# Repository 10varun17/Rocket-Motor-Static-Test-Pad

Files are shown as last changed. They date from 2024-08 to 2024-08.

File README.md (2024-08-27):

# Rocket-Motor-Static-Test-Pad
</br>
This project includes the work that I did during my internship at the Space Technology and Aeronautical Rocketry (STAR) Labs, India in 2022. The objective of my task in the internship was to design a Rocket Motor Static Test Pad for testing and acquiring the required data for the performance analysis of the high powered rocket motors. It is not an individual project. My project had two departments: Avionics and Mechanical Design. There were two members in the Mechanical Design Department and one member (that's me!) in the Avionics Department. I have added my internship report to this repo. Please go through the report to understand the work I did during the internship. The report is an individual report, but during the internship, I was told to put ~80% of my work (avionics) and 20% of my teammates' work in the report. It means that I do not have any contributions to the CAD designs that are presented in my report. My work in the project includes the Avionics work only.</br>

<h2>Notes</h2></br>
You need to have the softwares Proteus and Eagle EDA to open the files in the Circuit Design and PCB design sub-directories. However, I have put some images and pdfs to show my circuit and PCB designs.

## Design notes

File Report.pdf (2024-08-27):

## Internship Report on

# Design and Analysis of Rocket Motor Static Test Pad

## At STAR - Space Technology and Aeronautical Rocketry

## Varun Rayamajhi Avionics Intern Period: 20th August - 19th September

## Duration: 30 Days

INTERNSHIP REPORT | Varun Rayamajhi

## Rocket Motor Static Test Pad

### What is a rocket motor static test pad?

Rocket Motor Static Test Pad is a stationary mechanism designed to hold a rocket motor and conduct its static test fires, during which different parameters of its operation are measured and stored by avionics system for analyzing its performance. These parameters include thrust, chamber pressure, exhaust gas temperature, and so on. Following is a picture of rocket motoe static test pad:-

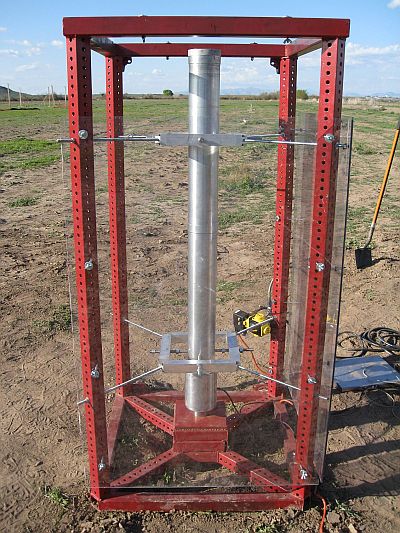
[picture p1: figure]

Figure 1: Rocket Motor Static Test Pad

### Basic Working Principle of Rocket Motor Static Test Pad

Rocket Motor Static Test Pad consists of two prominent components: Frame/Body and Avionics System.

Body
The body of a rocket motor static test pad is used to hold rocket motor statically during static test fires. Depending on the design, the rocket motor can be mounted horizontally or vertically. As well as that, the body of the test pad includes portability mechanism, if it has any. Additionally, it also includes structure to hold controlled fire extinguisher and avionics bay.

Avionics System
Avionics System is a major part of rocket motor static test pad. It is placed inside avionics bay. Avionics System is like the brain of the static test pad which controls the operation of rocket motor, data acquisition, and safety system. Avionics System consists of all electronic components such as temperature sensor, micro controller, load cell, and so on, which collectively work to conduct static test fires safely and store the acquired data.

Working
The experimental rocket motor is held into the motor mount of the test pad. All the electronics connections are made and verified and the electronics components are put inside the avionics bay. The load cell is mounted onto the central support frame. Igniter and sensors are put into their respective places; for instance, temperature sensor is placed near the combustion chamber if its purpose is to measure chamber temperature. To begin static test fires, a command is sent through micro controller to start ignition system. After ignition, the motor is fired up and the required data is collected by respective components and stored, if necessary, for future analysis. The testing ends automatically when the motor runs out of fuel whereas the data acquisition terminates when micro controller is powered off or by command, if there is any, from micro controller. This is the general working mechanism of rocket motor static test pad, but the working may differ with different types of static test pads. Some static test pads, for example, might have controlled fire extinguishing system while others may not have such system.

### Necessity of Rocket Motor Static Test Pad

Space missions are expensive and so are launch vehicles. Launch vehicles are used for performing scientific missions. Such expensive, yet useful vehicles, can’t be sent blindly to space for their missions. To ensure that the vehicles perform as intended on their missions, their static testings are inevitable. Static test pads allow the engineers to test rocket motors and analyze their performance parameters for further analyses, which enable them modify the rocket motor or nozzle or even fuel for best possible performance. Likewise, static tests allow engineers to scout for possible problems that may arise during the launch. It allows them to overcome such problems of the rocket motor beforehand. In all, static test pads are required for performance analysis of rocket motors as well as for high efficiency and economical reasons, too.

### Softwares Used

Following softwares were used for following purposes:-

Table 1: Softwares and their purposes

S.N. | Software | Purpose
1. | Fusion 360 | CAD Design, Assembly, and Simulation
2. | Proteus | Circuit Design and Simulation
3. | Arduino IDE | Code Development
4. | Eagle EDA | PCB designing
5. | MIT App Inventor | Mobile Application Development for remote controlling with mobile
6. | Processing | Graphical Interface Design for remote controlling with laptop

### Components Used

The components used in the static test pad and their purposes are tabulated below:-

Table 2: Mechanical Design components and their purposes
S.N. | Component | Purpose
1. | T-Slot Aluminum Bars | Structural purpose
2. | Fasteners | Connecting gusset plate to the bars
3. | Gusset Plates | Connecting all the bars with each other
4. | Avionics Bay Housing (Casing) | Holding all the electronics
5. | Motor Mount | Holding the rocket motor axially
6. | Ball Transfer Units | Facilitating the axial motion of the motor while it is burning
7. | Nuts | Connecting fasteners and gusset plates with the T-Slot bars.

Table 3: Avionics components and their purposes
S.N. | Component | Purpose
1. | Arduino Uno R3 | Microcontroller
2. | Button Type Load Cell | Measuring Thrust
3. | HX711 module | Converting analog signal from load cell to digital signal
4. | SD Card | Data Storage
5. | SD Card Module | Holding SD Card
6. | HC05 module | Creating bluetooth connection between microcontroller and laptop/mobile
7. | LEDs | Visual aid for safety purpose
8. | Push Button | For calibration purpose of load cell, if needed
9. | Buzzer | Auditory perception for safety purpose
10. | 2 channel 5V Relay Module | For delayed ignition system and for controlling fire extinguisher
11. | Batteries | Powering Arduino and electricity source for igniter and solenoid
12. | Nichrome Wire | Igniter
13. | Solenoid | For controlled fire extinguisher mechanism
14. | MAX6675 module with k-type thermocouple | Measuring exhaust gas temperature

### Architecture

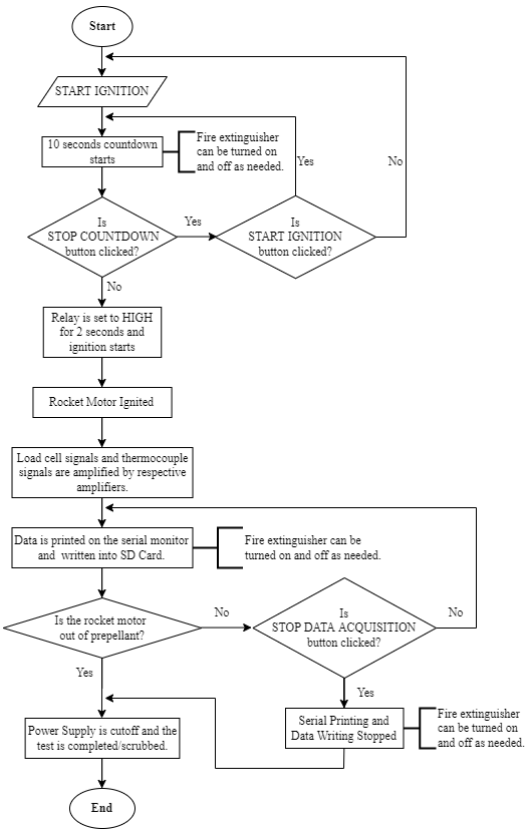
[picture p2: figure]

Figure 2: Flowchart of Avionics System

### Objectives

The objective of the internship was to design a static test pad for high-powered rocket motor. Following were the projected properties of the static test pad:-

1. Able to acquire and process the requires data
2. Real-time data transmission and reception
3. Data storage for future analysis
4. Good strength/weight ratio
5. Good aesthetics and ergonomics
6. Easy to assemble and dissemble
7. Easy to accommodate all electronics and power system conveniently
8. Prone to minimum errors

### Methodology

This report primarily focuses on the avionics of the static test pad.

Avionics
The anatomy of contents discussed in this section is as follows: (1) my approach to solving problem statement, (2) a small account of the components mentioned earlier, and (3) Features of Avionics System.
First thing I did before starting my work was reading the problem statement and finding out what I’m supposed to do. After finding the purpose of the problem statement, I made an algorithm (step-wise procedures) on how I’ll be working on the problem statement. Following is the procedure I followed for solving the problem statement:-
1. Research what type of data (parameters) is needed to analyze the performance of rocket motor.
2. Research about necessary sensors and other electronic components according to the parameters needed.
3. Finalize the electronic components.
4. Design circuit for load cell in Proteus.
5. Write sketch for load cell in Arduino IDE.
6. Simulate load cell in Proteus.
7. Repeat 4, 5, and 6 for other components.

8. Design circuit containing all electronic components in Proteus.
9. Write Arduino sketch and simulate circuit in Proteus.
10. If problems arise, work on them. If not, design PCB schematic in Eagle.
11. Calculate total cost of avionics system.

In every step of the aforementioned algorithm, I was always brainstorming about the problems that may arise during motor test and whether the avionics system can help solve those problems. Afterwards, I worked on solving the problems.
After conducting research, I finalized the components mentioned earlier in the report. I used Arduino Uno R3 as a microcontroller. For measuring thrust, our team decided to use button type load cell. For load cell amplifier, I used HX711 module. Regarding temperature sensors, I had many options, but PT100 sensor and k-type thermocouple were the major contenders. I decided to use k-type thermocouple over PT100 because of its wide temperature range (0

◦

C - 1024◦
C) and a little bit
low cost compared to PT100 sensor. For thermocouple amplifier, I had the options of AD595 and MAX6675 amplifiers. I chose MAX6675 amplifier mainly because of its high in-built resolution of 12 bits as compared to 10 bit of AD595 and also because of its cheap cost than AD595. For data storage, I used micro SD Card module. LEDs were used as visual aid for safety purpose. Three LEDs were used: Green, Yellow, and Red. Green LED indicates that the temperature recorded by thermocouple is within the range. Red LED indicates that the temperature is beyond the limit. Continuously glowing Yellow LED indicates that the ignition system hasn’t started yet while a blinking yellow LED indicates that the ten seconds countdown for ignition is going on. LOW yellow LED indicates that the motor has been ignited and the test is being carried out. Likewise, I have also used buzzer, which produces sound when the temperature crosses the limit. For remotely controlling ignition system and fire extinguisher, I have used 2 channel 5V relay module. For ignition system, the relay module acts as a one time switch only while it acts as a switch for fire extinguisher for whole duration of rocket motor test. Solenoid is used for controlling the handle of fire extinguisher. 32 AWG Nichrome 60 wire is used as an igniter. For remote controlling, I have used HC05 bluetooth module.

The avionics system has a remote controlled ignition system. Using button controlled ignition system was an ad-hoc, so I thought of making remote controlled ignition system. Ignition system can be initiated by typing command in serial monitor or graphical interface developed using Processing or mobile application. From now on in the report, I refer these three methods of remotely controlling avionics as “THREE methods”. If any problem occurs during the countdown, the ignition system can be halted by any of the THREE methods. After solving the problem, ignition system can be started again by same process as earlier. The idea of stopping countdown and halting ignition system was suggested by the shaper Harsh Patel. Below is the code specific to ignition system in my main sketch:-

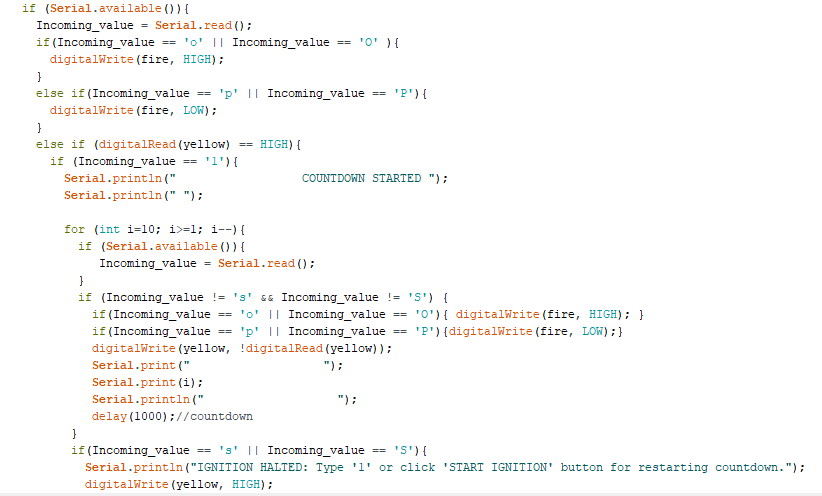
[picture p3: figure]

Figure 3: Code specific to Ignition System and Fire Extinguisher

The above code also contains commands to control fire extinguisher. Lines near the word “fire” are specific to fire extinguisher.
One problem that may arise during motor test is the collection of false/invalid data when a problem occurs during the test such as motor sliding off the motor mount due to lack of pre-check of motor clamps placement, fire (unwanted), and so on. In such case, data acquisition can be stopped by any of the THREE methods. Actually, it is one of the problems that I thought it might arise during the test. Below is the code specific to stopping data acquisition:-

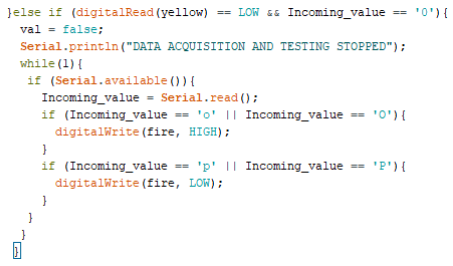
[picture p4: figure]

Figure 4: Code specific to stopping data acquisition

Static test fires are meant to analyze the performance parameters of rocket motor. Thus, data storage is important in static testing. For data storage, I have used SD Card, which stors data in .txt file.

For data analysis, Microsoft Excel can be used. I have used “,” as a delimiter between different columns of data, so the data stored in .txt file can be imported from Excel easily. Thermocouple measures exhaust gas temperature and load cell measures thrust. With information of thrust, exhaust gas temperature, and specifications of the rocket motor, we can calculate different parameters for analyzing the performance of the motor. For example, chamber pressure, total thrust, average thrust, maximum thrust, specific impulse, effective exhaust velocity, burn time, etc. Below is the code specific to data storage:-

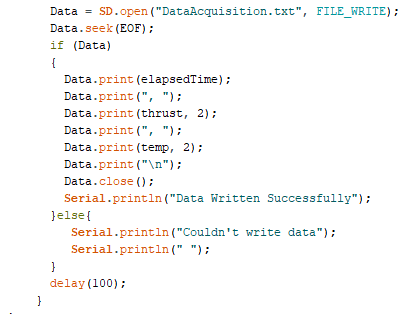
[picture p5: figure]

Figure 5: Code specific to Data Storage and use of “," as a delimiter

In the Arduino sketch, I’ve used different values (letters and numbers) as commands for Arduino to perform tasks of ignition, fire extinguisher, and data acquisition stoppage accordingly. Remembering different variables might be troublesome and not too practical, so I used Processing software to generate a graphical interface through which commands can be sent by clicking buttons when the laptop’s bluetooth is connected to HC05 bluetooth module. For example, pressing “START IGNITION” button will send letter ‘1’ to Arduino through HC05 module, which means arduino will start ignition as it is programmed to do so only once on receiving ‘1’. Below are pictures of the interface generated by Processing Software and Processing code specific to sending commands to arduino:-

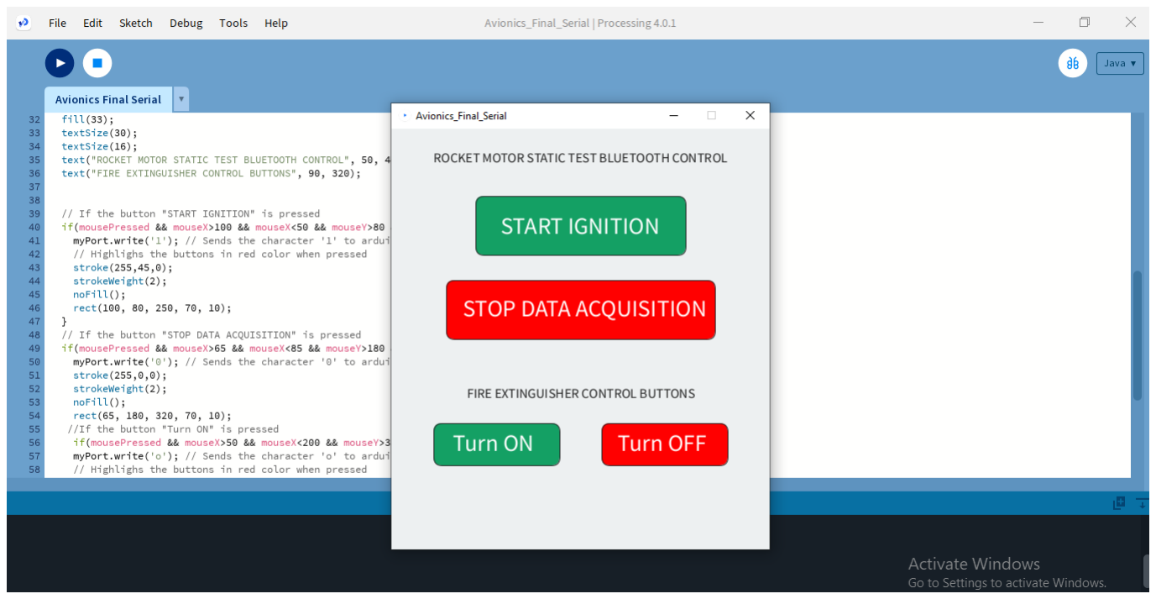
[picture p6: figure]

Figure 6: Graphical Interface generated with Processing Software

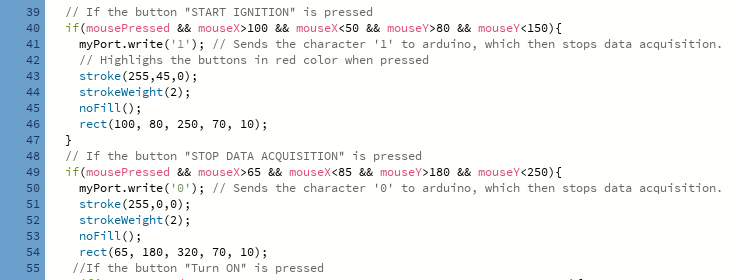
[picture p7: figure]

Figure 7: Code specific to sending commands to Arduino through HC05

I also thought of controlling avionics system using mobile phone. At first, I had planned to use Blynk application (legacy version), but I found that the legacy version had been shut down. With the new version, I didn’t find any options for bluetooth connection, and I felt the new version to be a bit difficult than the legacy version. Therefore, I switched to another method of controlling avionics from mobile phone. I used MIT App Inventor to create a simple mobile application which sends commands (in the form of text) to Arduino when the mobile is connected with HC05 bluetooth module. Below are the pictures of mobile application and designer view and code blocks view of application in MIT App Inventor:-

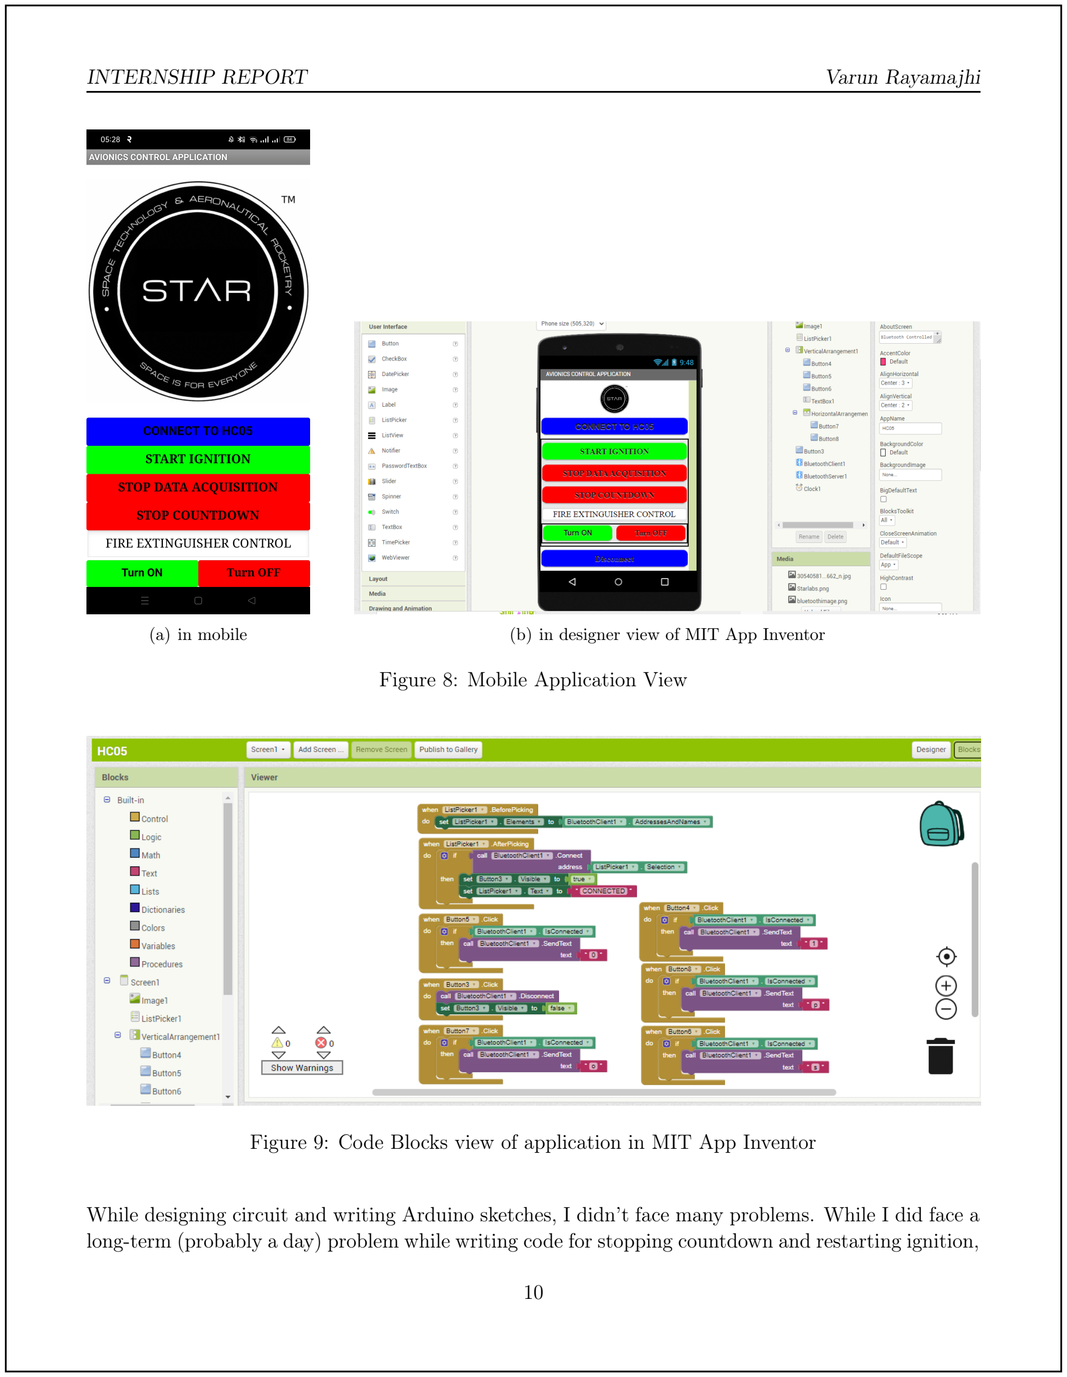
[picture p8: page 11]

(a) in mobile | (b) in designer view of MIT App Inventor

Figure 8: Mobile Application View

Figure 9: Code Blocks view of application in MIT App Inventor

While designing circuit and writing Arduino sketches, I didn’t face many problems. While I did face a long-term (probably a day) problem while writing code for stopping countdown and restarting ignition,

I didn’t face any other major problems. To solve the mentioned problem, I used hit and trial method: I was trying different loops, functions, etc until I got it the way I wanted it. As mentioned earlier in the algorithm of my work, I designed circuit for specific components first. When I completed simulating all components of avionics in Proteus, I combined other circuits in the Proteus file containing load cell circuit. While combining circuits, I chose same pins for each components. For example, if I had used pin 7 for buzzer while simulating it individually, I’d also use pin 7 for buzzer in the main circuit. This strategy of designing main circuit helped me with the code too. For code, I didn’t have to write it from scratch. I just had to look for specific portion of code from individual codes for each components and use that portion in the main code. I didn’t face any problem in simulation of my main circuit probably due to my strategy of “integrating” individual codes and individual circuits. One advantage I had in circuit simulation was that I was working in two laptops simultaneously which helped me avoid problems of connecting wires to different pins in the main circuit than those pins used in individual circuits. On the other hand, my first draft of PCB design was not practical. The shaper Harsh Patel suggested me to make PCB design as realistic and simple as possible. Then, I made few changes to the first draft of PCB design, but the second draft had some incompleteness because I didn’t use screw terminals for connecting load cell to HX711 module. Lastly, I added screw terminals, and this time, my PCB design was completed. Below are the pictures of Proteus Circuit Design and PCB design:-

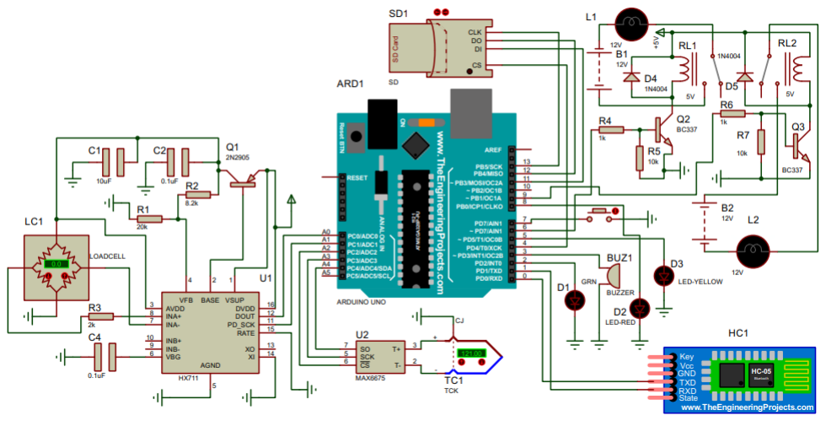
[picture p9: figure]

Figure 10: Circuit Design

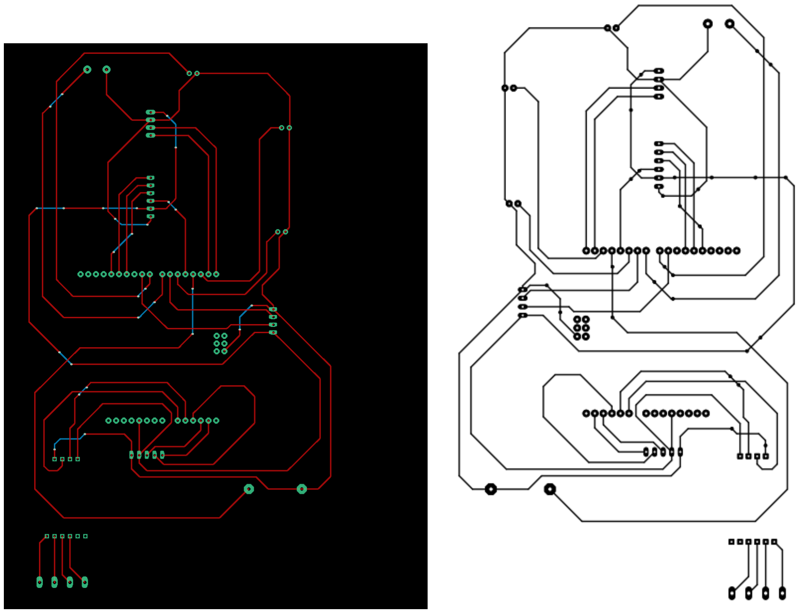
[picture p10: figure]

Figure 11: PCB Design

Guide for how to build Avionics:

1. Research what parameters you need to analyze for performance analysis of rocket motor.
2. Research about electronic components according to the parameters and your other needs such as safety system.
3. Design your circuit in Proteus. Before designing whole circuit, design circuits for individual electronic components first.
4. Write your sketch in Arduino IDE and upload hex file to Proteus Circuit.
5. Simulate your circuit in Proteus.
6. If the simulation is working as intended, design the PCB in Eagle EDA for manufacture purpose. If not, solve the problem.

7. Assemble all electronic components in the PCB and upload sketch to your microcontroller.

Mechanical Design
The mechanical design team chose T-Slot Aluminum Bars over normal bars because of their flexible design, reliable strong structure, and fast and precise assembly. Moreover, using these bars will rule out the use of welding. Design team used fasteners, which are specially designed for T-slots. They are used to connect gusset plate to the bars. The design team included L gussets, Box gussets, and T gussets for connecting all the bars with each other. An avionics bay is a box that holds all the electronics such as the printed circuit board, The design team has used a glass cover on avionics bay housing to facilitate clear view of electronics from outside. Likewise, motor mount will hold the motor axially and the ball transfer units will be attached to this shaft to facilitate the axial motion of the motor while it is burning. Ball transfer units are omni-directional load-bearing spherical balls mounted inside a restraining fixture. They are identical in principle to a computer trackball (a pointing device). Typically, the design involves a single large ball supported by smaller ball bearings. There will be M7 nuts, which will be used to connect the fasteners and gusset plates with T-slot bars.

Guide for how to build Design

1. Research on the basic components which you’ll require to make the Static Test Pad.
2. Select the components you require and make a CAD model of each of them using Fusion 360.
3. Assemble all the components using rigid joints in Fusion 360.
4. Simulate the model of the test pad using Fusion 360 by putting necessary constraints and generating manual and automatic contacts. Then, give appropriate load to the place of load cell according to the class of motor for which the test pad is made.

Following are some pictures of the components used in the design of the static test pad:-

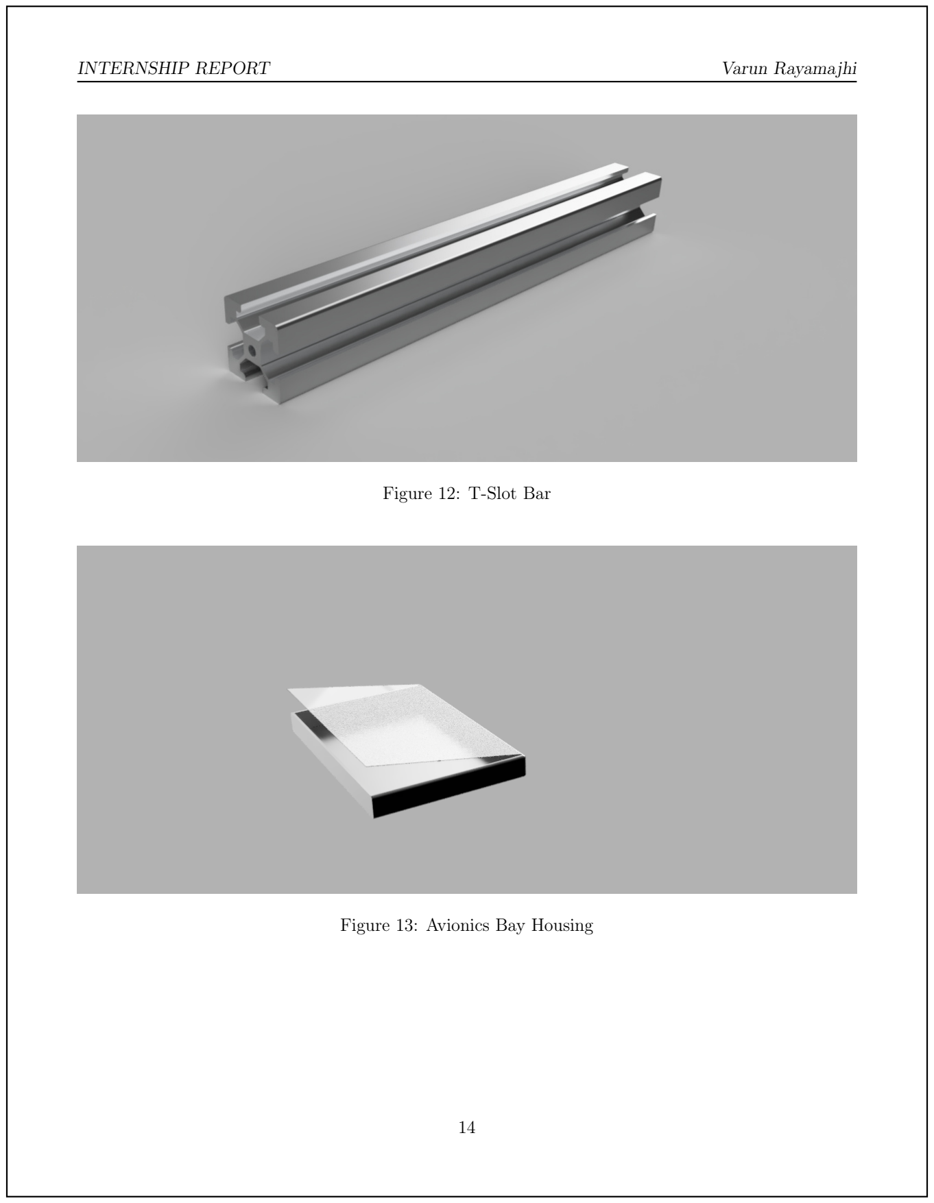
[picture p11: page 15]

Figure 12: T-Slot Bar

Figure 13: Avionics Bay Housing

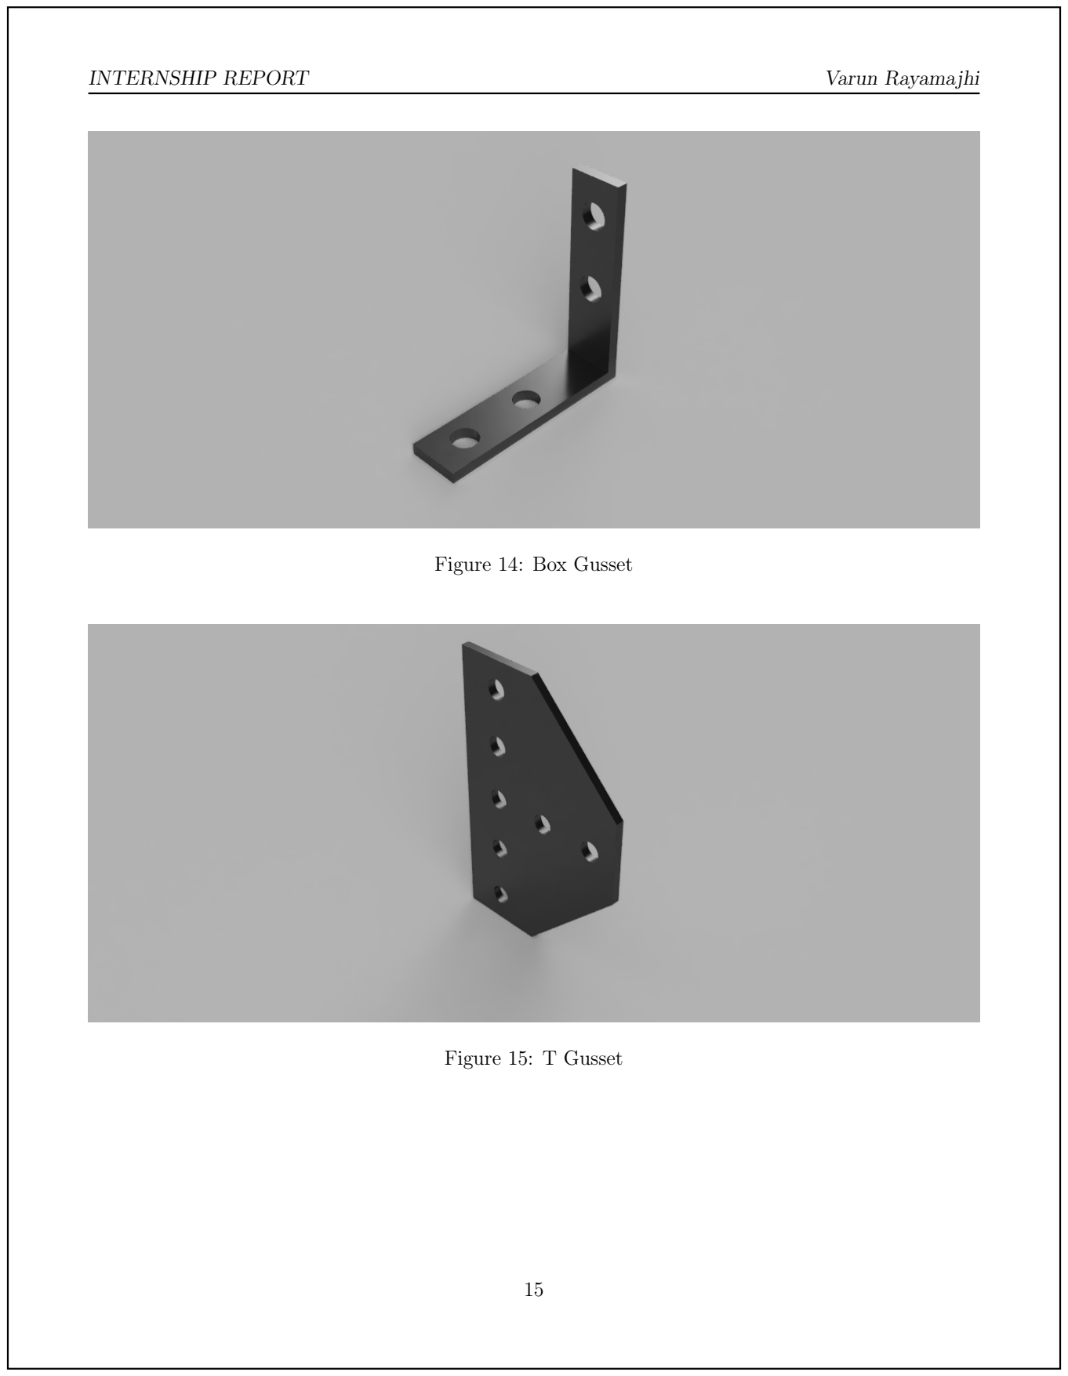
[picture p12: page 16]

Figure 14: Box Gusset

Figure 15: T Gusset

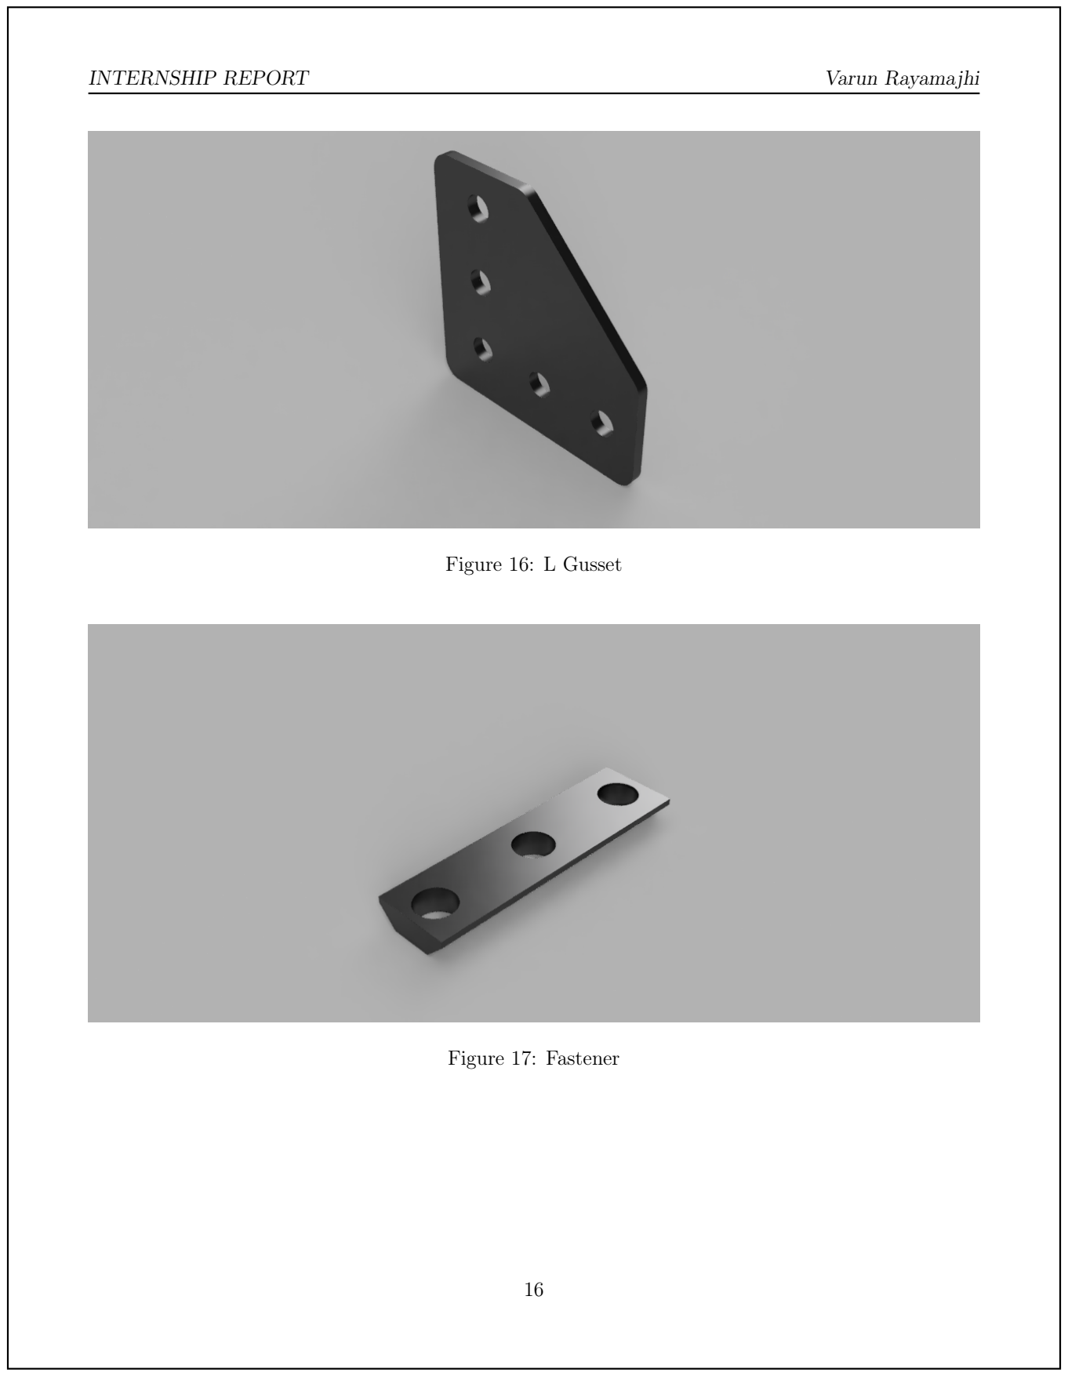
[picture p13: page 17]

Figure 16: L Gusset

Figure 17: Fastener

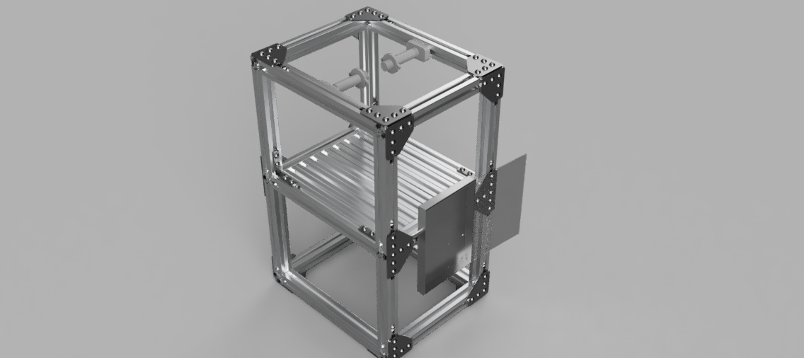
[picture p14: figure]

Figure 18: Assembly of the Static Test Pad

### Cost

The costs of components used in mechanical design and avionics of the static test pad are tabulated below:-

Table 4: Total Cost of components used in Mechanical Design
S.N. | Components | Dimensions | Quantity | Cost [INR]
1. | T-Slot Aluminum Bars | 235mm*30mm*30mm | 8 | 592.2
2. | T-Slot Aluminium Bars | 305mm*30mm*30mm | 20 | 1921.5
3. | T-Slot Fasteners | 25mm*13mm*5mm | 52 | 3640
4. | Gusset Plates (Corner) | 55mm*55mm*3mm | 16 | 80
5. | Gusset Plates (3 edged) | 100mm*55mm*3mm | 4 | 24
6. | Box Gusset Plate | 55mm*55mm*3mm | 4 | 14
7. | Avionics Bay Housing | 137.5mm*203mm*15mm | 1 | 33.48
8. | Ball Transfer Unit | 40mm dia; 60mm length | 4 | 560
9. | Motor Mount Shafts | 95mm*24mm | 4 | 460
10. | Nuts | M7 15mm | 52 | 104
11. | Total | | | 7429.18

Table 5: Total Cost of electronic components in Indian and Nepali markets
S.N. | Component | Cost (Indian Market) [INR] | Cost (Nepali Market) [NPR]
1. | Arduino Uno R3 | 800 | 1150
2. | HX711 Module | 79 | 150
3. | Button Type Load Cell | 6000 | 9600
4. | SD Card Module | 71 | 180
5. | SD Card | 300 | 450
6. | HC05 Bluetooth Module | 210 | 710
7. | LEDs | 5 | 15
8. | Push Button | 10 | 10
9. | Buzzer | 40 | 25
10. 2 Channel 5V Relay | Module | 130 | 280
11. | Batteries | 236 | 380
12. | Nichrome Wire | 35 | 60
13. | Solenoid | 600 | 750
14. MAX6675 module with | k-type thermocouple | 400 | 435
15. | Total | INR 8916 | NPR 14195 (INR 8872)

### Sketches

The link for Processing Software sketch is HERE. (https://bit.ly/3BLhdq1) The link for Arduino IDE Software sketch is HERE. (https://bit.ly/3UhBoDk)

### Observation

Circuit design in Proteus software was correct as well as the Arduino sketch. Circuit simulation was working properly in Proteus. As expected, countdown was of ten seconds and ignition duration was of two seconds. The fire extinguisher could be turned on and off any time of the simulation. The sensor readings were collected at the rate of fifty samples per second. Data Acquisition Stoppage system was also working properly. PCB design was also deemed correct by the shaper. Since I didn’t have HC05 bluetooth module, I couldn’t test mobile application and laptop with HC05, but I did check mobile application by modifying code blocks to start countdown in mobile screen when “START IGNITION” was clicked so as to allow the buttons to work when mobile is not connected to bluetooth, and it was working properly. The total cost of electronic components is estimated at INR 8916 in the Indian market and INR 8872 (NPR 14195) in the Nepali market.

### Results

This report elaborates the avionics system of rocket motor static test pad. Circuit was simulated multiple times to validate whether it’s working properly or not. Mobile Application and Graphical

Interface were generated using MIT App Inventor and Processing software for mobile and laptop respectively. These applications are expected to be useful in real time static testing. I also expect them to work as intended when mobile or laptop is connected to HC05 bluetooth module.

### Conclusion

Avionics System for Static Test Pad with predefined requirements was successfully designed and simulated virtually. There were also features other than the predefined ones. These features include stopping data acquisition, stopping countdown, remote controlled ignition system, and controlled fire extinguishing. In all, an avionics system with reasonable price for the features it provides was designed successfully.

### Precautions

Following precautions need to be considered while performing static test fires:-

1. Keep a safe distance from static test pad during static testing.
2. Do not perform static testing in or near residential area.
3. Perform under proper supervision if you are not experienced in static tests.
4. Be aware of local government’s policies about rocket motor testing.
5. Be sure to check all the electrical connections in the avionics bay.
6. Connect RXD and TXD pins of HC05 to TXD and RXD pins of arduino respectively only after uploading code to Arduino.

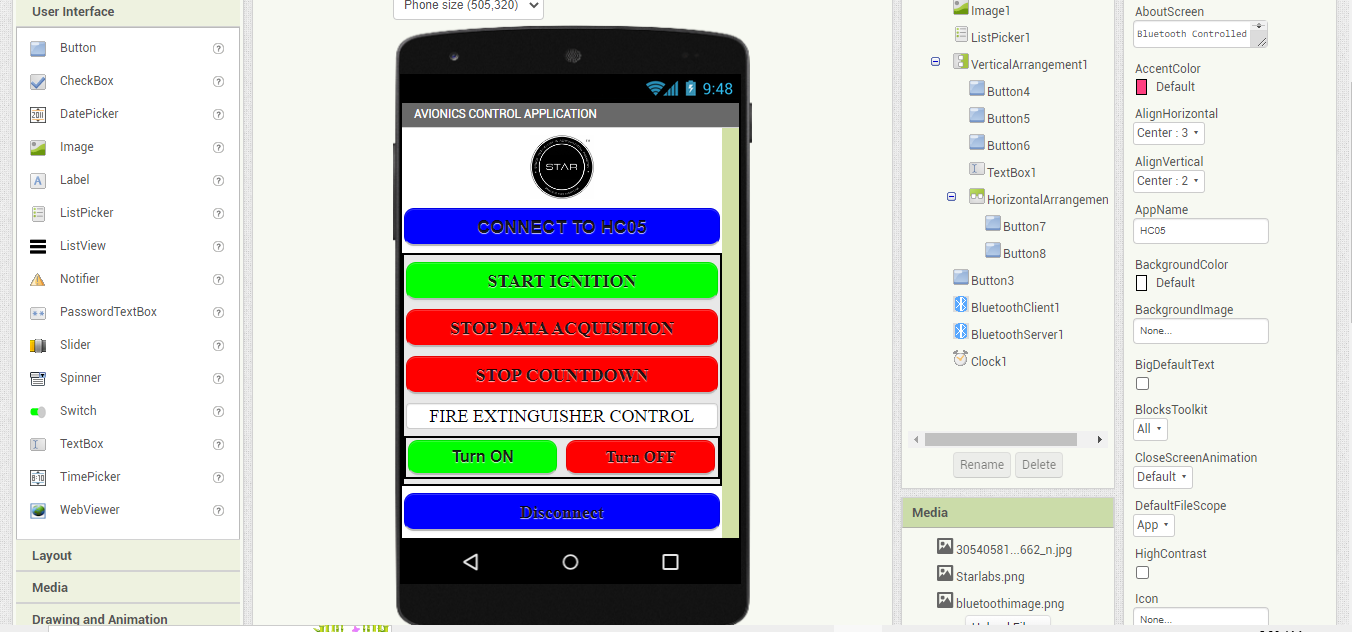
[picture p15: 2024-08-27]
product_demo/mit_app_inventor_images/Designer.png

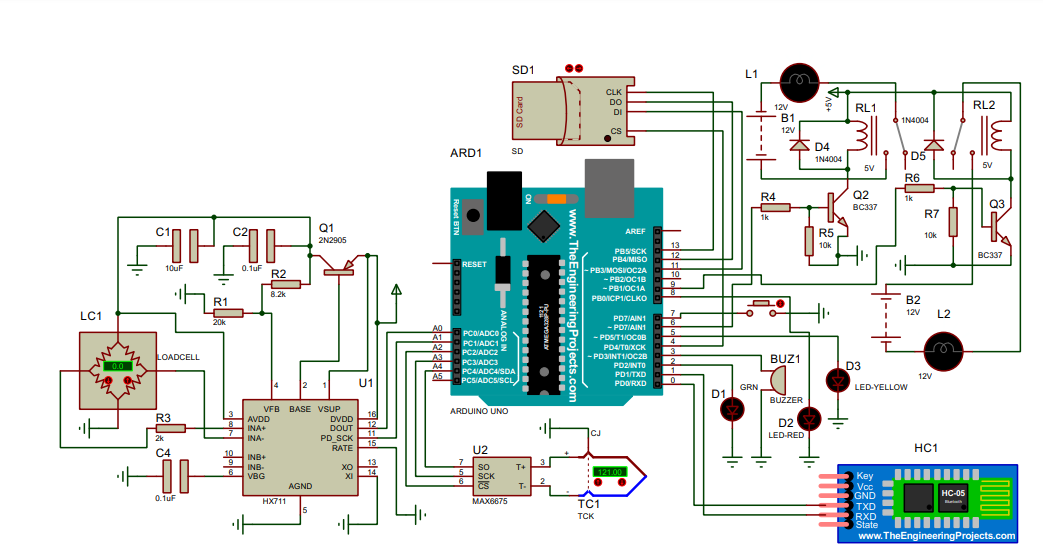
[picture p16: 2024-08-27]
src/circuit_design/design_pic.png

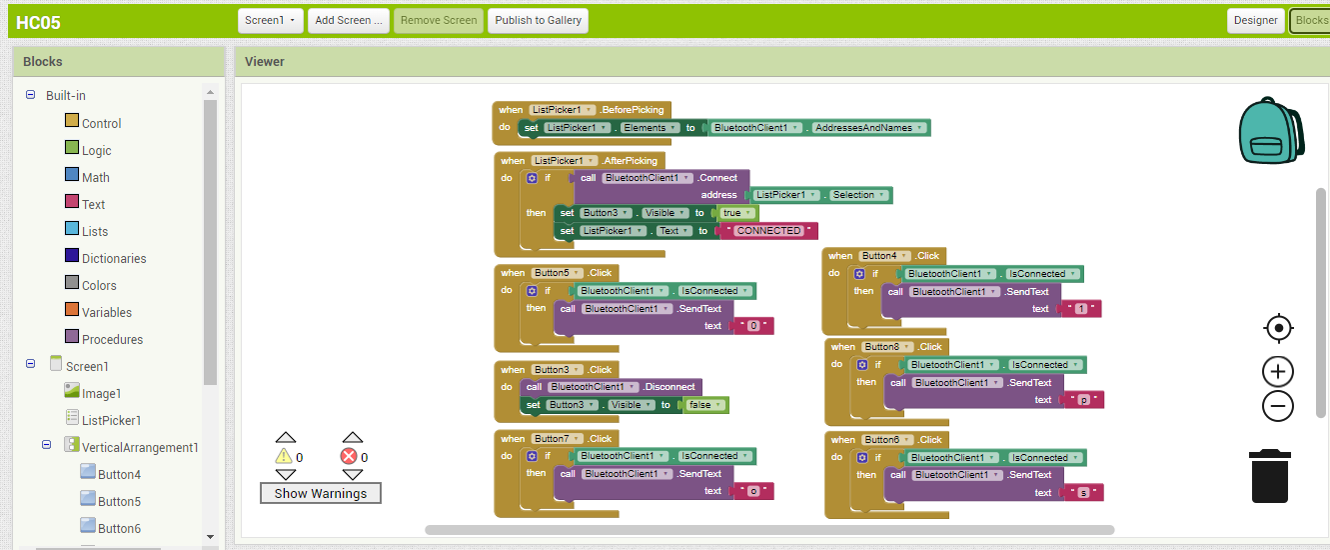
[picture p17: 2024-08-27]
product_demo/mit_app_inventor_images/blocks.png

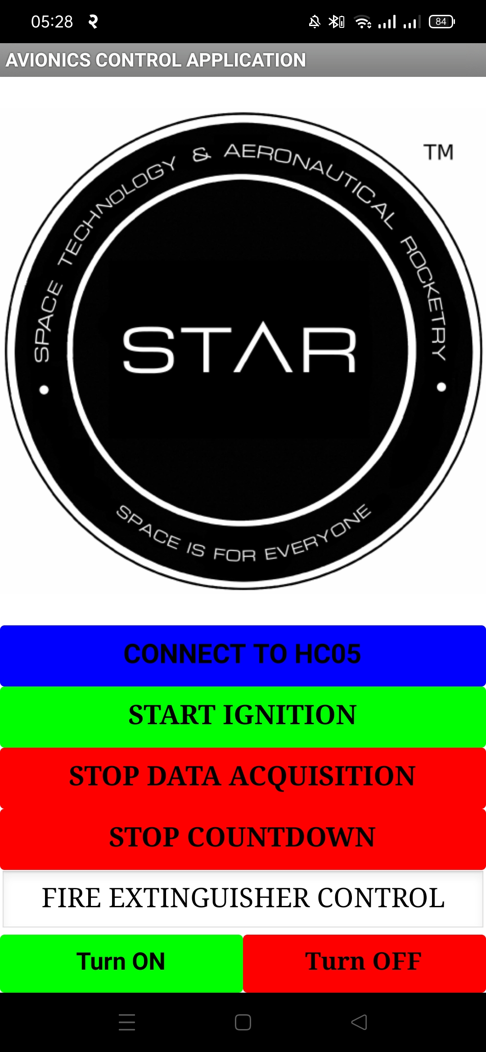
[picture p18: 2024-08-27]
product_demo/mit_app_inventor_images/mobileapp.jpg

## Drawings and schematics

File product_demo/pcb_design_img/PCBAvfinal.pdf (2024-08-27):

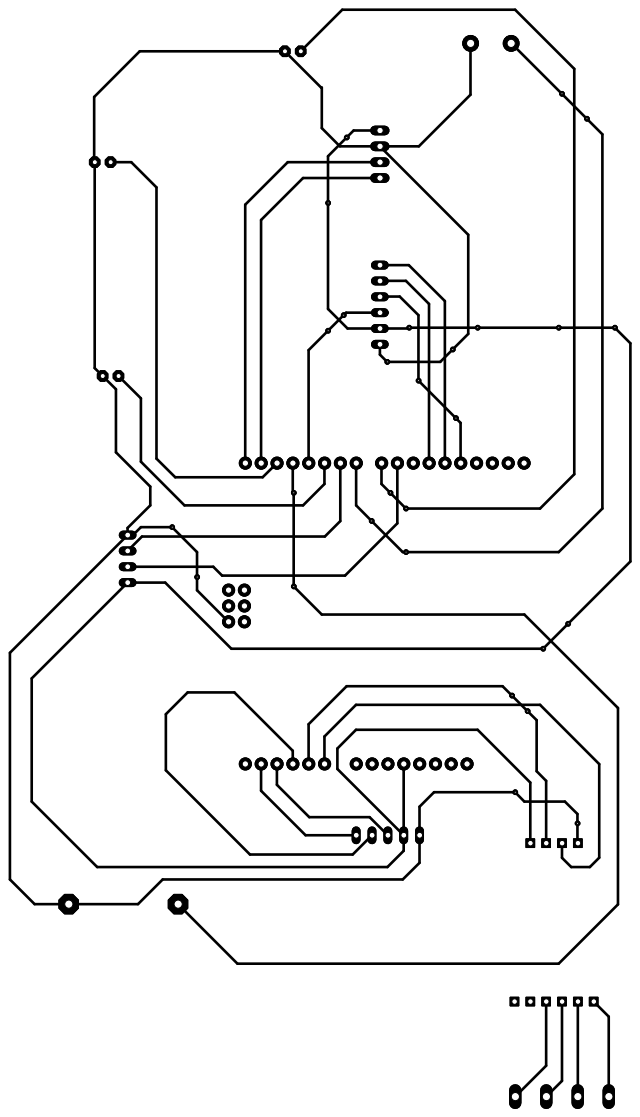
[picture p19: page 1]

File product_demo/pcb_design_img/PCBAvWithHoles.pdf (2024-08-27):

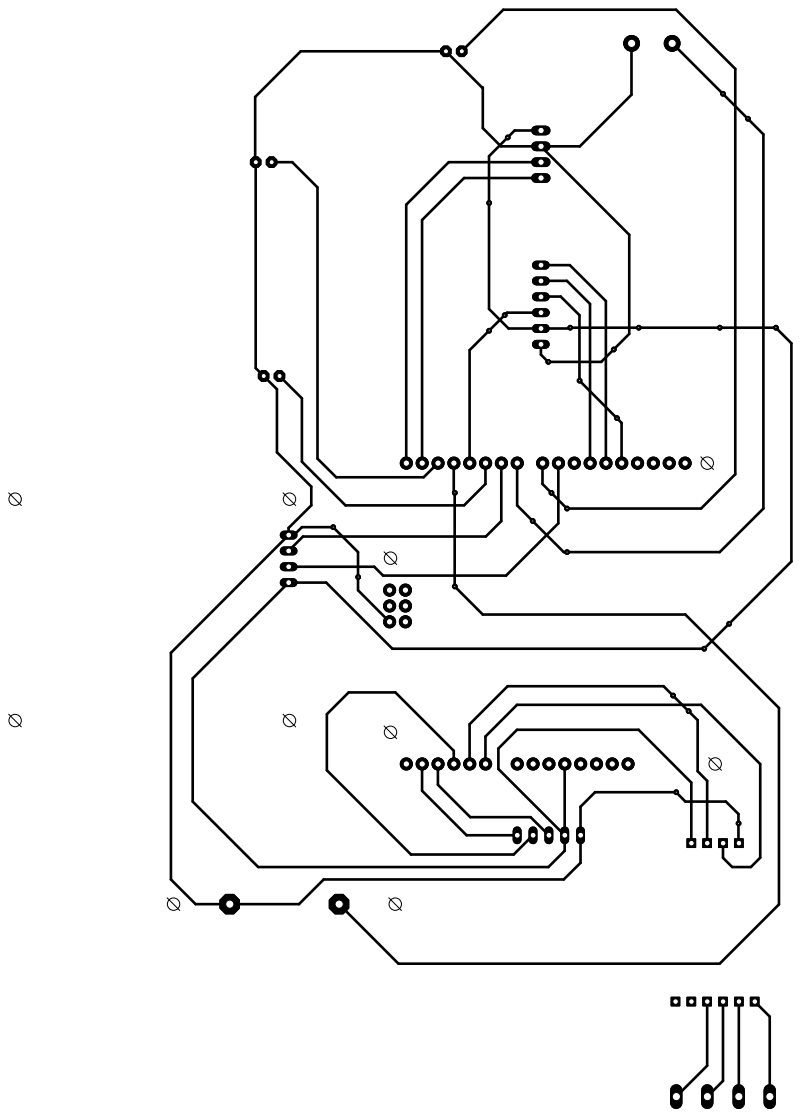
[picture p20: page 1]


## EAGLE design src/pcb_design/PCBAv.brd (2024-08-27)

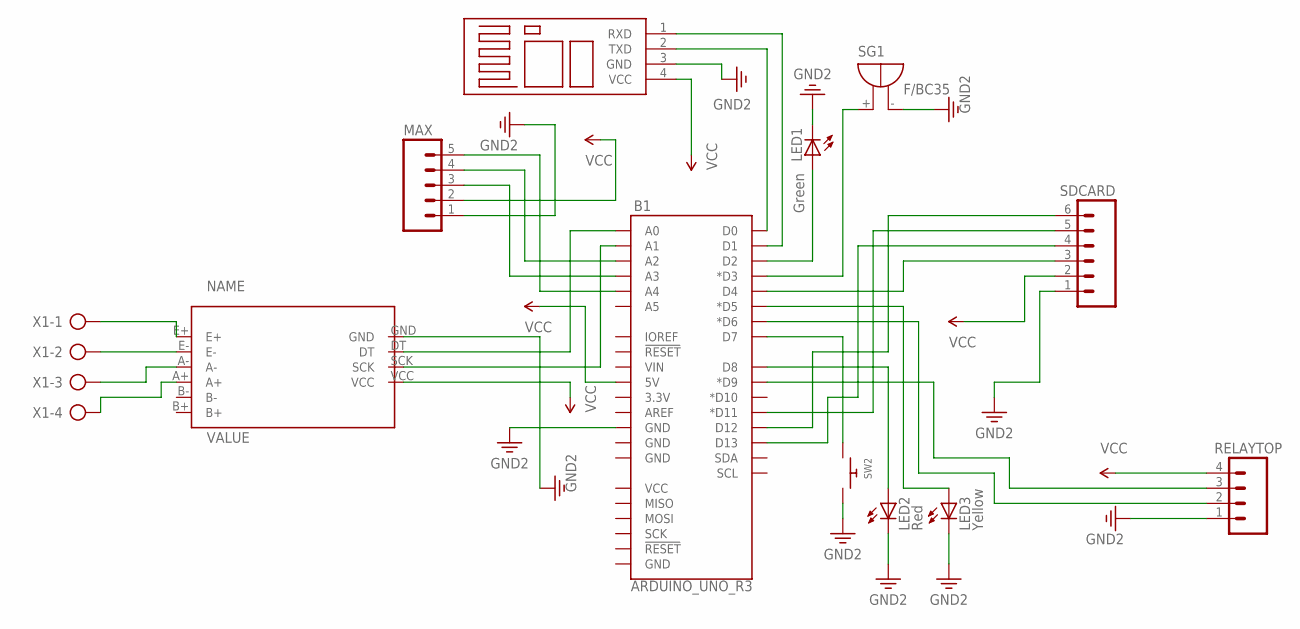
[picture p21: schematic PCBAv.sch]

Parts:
B1: ARDUINO_UNO_R3; ARDUINO_R3
HC05: BLUETOOTH
LED1: Green; LED5MM
LED2: Red; LED5MM
LED3: Yellow; LED5MM
MAX: M05; 05P
RELAYTOP: M04; 04P
SDCARD: M06; 06P
SG1: F/BC35
SW2: SWITCH_PUSHBUTTONEVQ-PE; TACT_PANA-EVQ
U$1: HX711
X1: AK300/4

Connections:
3.3V: B1.GND@4 (GND), HC05.3 (GND), LED1.K (C), LED2.K (C), LED3.K (C), MAX.1, RELAYTOP.1, SDCARD.1, SG1.-, SW2.P$2, U$1.GND
unnamed: B1.D1, HC05.1 (RXD)
unnamed: B1.A0, U$1.DT
unnamed: B1.D0, HC05.2 (TXD)
unnamed: B1.D7, SW2.P$1
unnamed: U$1.E+, X1.1
unnamed: U$1.E-, X1.2
unnamed: U$1.A-, X1.3
unnamed: U$1.A+, X1.4
unnamed: B1.A4, MAX.5
unnamed: B1.A2, MAX.4
unnamed: B1.A3, MAX.3
unnamed: B1.D4, SDCARD.3
unnamed: B1.D11 (*D11), SDCARD.5
unnamed: B1.D13, SDCARD.4
unnamed: B1.D12, SDCARD.6
unnamed: B1.D8, LED2.A
unnamed: B1.D2, LED1.A
unnamed: B1.D5 (*D5), LED3.A
unnamed: B1.D3 (*D3), SG1.+
unnamed: B1.D9 (*D9), RELAYTOP.3
unnamed: B1.D6 (*D6), RELAYTOP.2
unnamed: B1.A1, U$1.SCK
VCC: B1.5V, HC05.4 (VCC), MAX.2, RELAYTOP.4, SDCARD.2, U$1.VCC

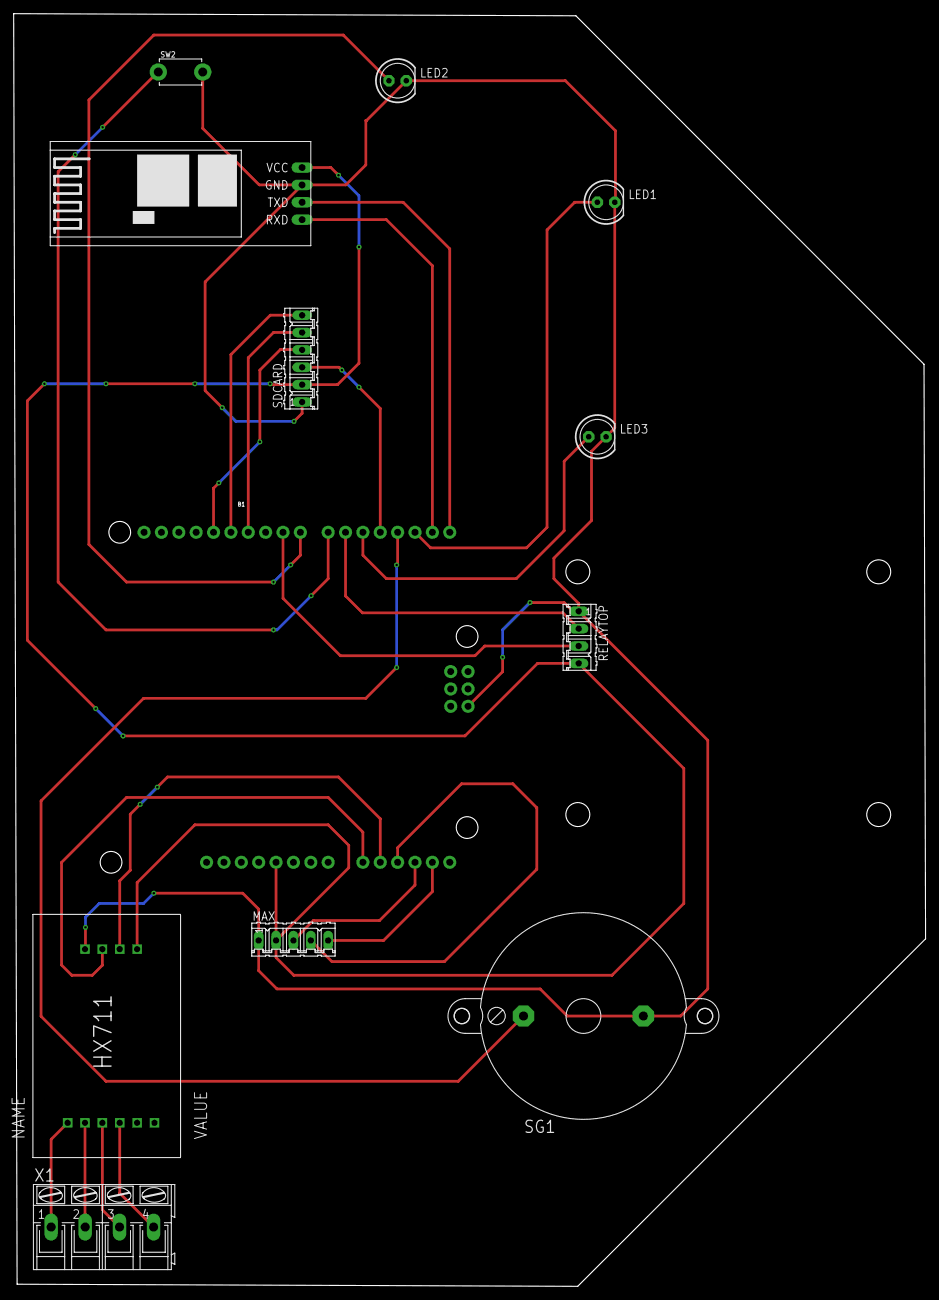
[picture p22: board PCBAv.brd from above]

Board: 2 copper layers, 133.4 x 186.1 mm, 12 parts (0 on the bottom side), 24 nets.

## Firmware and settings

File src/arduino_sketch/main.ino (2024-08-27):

#include "HX711.h"
#include <Wire.h>
#include <SD.h>

#define DOUT  A0
#define CLK   A1
#define SO    A4
#define CS    A2
#define SCK   A3
#define G_led 2 
#define R_led 8
#define buzzer 3
#define yellow 5
#define ignition 6
#define fire 9

float temp_c, temp; // Variables for temperature readings
char Incoming_value; // Variable to store incoming serial commands
char stopsignal; // Unused variable
int sw = 7; // Switch pin
int i = 10; // Countdown variable
float mass; // Mass measurement variable
float thrust; // Thrust calculation variable
float calibration_factor = -134715; // Calibration factor for load cell
unsigned long startTime; // Start time for data acquisition
unsigned long elapsedTime; // Elapsed time during data acquisition
boolean val = false; // Flag to control data acquisition loop

HX711 scale(DOUT, CLK); // HX711 load cell instance

int CSK = 4; // Chip select pin for SD card
File Data; // File object for SD card operations

void setup()
{
    // Initialize serial communication
    Serial.begin(9600);
    Serial.println("======= ROCKET MOTOR STATIC TEST =======");
    Serial.println(" ");
    
    // Initialize pins for load cell
    pinMode(CLK, OUTPUT);
    pinMode(sw, INPUT_PULLUP);
    scale.set_scale();
    scale.tare();
    long zero_factor = scale.read_average();
    
    // Initialize SD card
    pinMode(CSK, OUTPUT);
    Serial.println("Initializing SD Card");
    if (!SD.begin(CSK))
    {
        Serial.println("NO SD CARD DETECTED. Please insert SD Card and reset the device");
        Serial.println(" ");
    }
    else
    {
        Serial.println("Initialization Done"); 
        Serial.println(" ");
    }
    delay(1000);
    Serial.println("Please read control options before starting ignition.");
    
    // Initialize pins for relay and other components
    pinMode(yellow, OUTPUT);
    digitalWrite(yellow, HIGH);
    pinMode(ignition, OUTPUT);
    pinMode(fire, OUTPUT);
    digitalWrite(fire, LOW);
    Serial.println("Click 'START IGNITION' or type '1' on the serial monitor to start ignition.");
    delay(1000);
    Serial.println(" ");
    Serial.println("Click 'STOP DATA ACQUISITION' or type '0' on the serial monitor to stop data acquisition.");
    Serial.println(" ");
    delay(1000);
    Serial.println("o = Turn on fire extinguisher");
    Serial.println("p = Turn off fire extinguisher");
    delay(2000);
    Serial.println("Controlled Fire Extinguisher Enabled");
    Serial.println(" ");
    Serial.println("Now start testing rocket motor,");
    Serial.println(" ");
    
    // Initialize pins for thermocouple and LED indicators
    pinMode(R_led, OUTPUT); 
    pinMode(G_led, OUTPUT); 
    pinMode(buzzer, OUTPUT);  
}

void loop()
{
    // Check for incoming commands from serial monitor
    if (Serial.available())
    {
        Incoming_value = Serial.read();
        // Command to turn on fire extinguisher
        if (Incoming_value == 'o' || Incoming_value == 'O')
        {
            digitalWrite(fire, HIGH);
        }
        // Command to turn off fire extinguisher
        else if (Incoming_value == 'p' || Incoming_value == 'P')
        {
            digitalWrite(fire, LOW);
        }  
        // Start countdown if '1' is received and yellow LED is high
        else if (digitalRead(yellow) == HIGH)
        {
            if (Incoming_value == '1')
            {
                Serial.println("                  COUNTDOWN STARTED ");
                Serial.println(" ");
                // Countdown loop
                for (int i = 10; i >= 1; i--)
                {
                    if (Serial.available())
                    {
                        Incoming_value = Serial.read();
                    }
                    // Check if 's' is received to stop ignition
                    if (Incoming_value != 's' && Incoming_value != 'S')
                    {
                        // Control fire based on commands
                        if (Incoming_value == 'o' || Incoming_value == 'O')
                        {
                            digitalWrite(fire, HIGH);
                        }
                        if (Incoming_value == 'p' || Incoming_value == 'P')
                        {
                            digitalWrite(fire, LOW);
                        }
                        digitalWrite(yellow, !digitalRead(yellow));
                        Serial.print("                   ");
                        Serial.print(i);
                        Serial.println("                   ");
                        delay(1000); // Countdown delay
                    }
                    // Stop ignition if 's' is received
                    if (Incoming_value == 's' || Incoming_value == 'S')
                    {
                        Serial.println("IGNITION HALTED: Type '1' or click 'START IGNITION' button for restarting countdown.");
                        digitalWrite(yellow, HIGH);
                    }
                }
                // Proceed with ignition if not stopped
                if (Incoming_value != 's' && Incoming_value != 'S')
                {
                    Serial.println(" "); 
                    Serial.print("              ");
                    Serial.println("GET SET GO");
                    Serial.println(" ");
                    digitalWrite(yellow, LOW);
                    digitalWrite(ignition, HIGH);
                    Serial.println("Relay is set to HIGH for 2 seconds.");
                    Serial.println("Rocket Motor Igniting");
                    delay(2000); // Ignition duration
                    digitalWrite(ignition, LOW);
                    Serial.println("Relay is set to LOW");
                    Serial.println(" ");
                    Serial.println("ROCKET MOTOR IGNITED");
                    Serial.println("DATA ACQUISITION STARTED");
                    Serial.println(); 
                    startTime = millis(); // Record start time for data acquisition
                    val = true; // Enable data acquisition flag
                }
            }
            else
            {
                val = false; // If '1' is not received, disable data acquisition
            }
        }
    }
    // Stop data acquisition if '0' is received and yellow LED is low
    else if (digitalRead(yellow) == LOW && Incoming_value == '0')
    {
        val = false;
        Serial.println("DATA ACQUISITION AND TESTING STOPPED");
        // Stay in loop until reset if '0' is received
        while (1)
        {
            if (Serial.available())
            {
                Incoming_value = Serial.read();
                // Control fire based on commands
                if (Incoming_value == 'o' || Incoming_value == 'O')
                {
                    digitalWrite(fire, HIGH);
                }
                if (Incoming_value == 'p' || Incoming_value == 'P')
                {
                    digitalWrite(fire, LOW);
                }
            }
        }
    }
    
    // Perform data acquisition if val is true
    if (val == true)
    {
        scale.set_scale(calibration_factor); // Set scale with calibration factor
        mass = scale.get_units(5); // Get mass measurement
        thrust = mass * 9.8; // Calculate thrust
        elapsedTime = millis() - startTime; // Calculate elapsed time
        Serial.print(elapsedTime);
        Serial.print(" | ");
        Serial.print("Thrust = ");
        Serial.print(thrust, 5);
        Serial.print(" N");
        Serial.print(" | ");
        Serial.print("Temperature = ");
        temp_c = Thermocouple_read(); // Read temperature from thermocouple
        if (isnan(temp_c))
        {
            Serial.print("Connect");
            Serial.println("Thermocouple");
            loop(); // Restart loop if thermocouple reading is invalid
        }
        Serial.print(temp_c, 2);
        Serial.print("C");
        Serial.println();   
        
        // Control LED and buzzer based on temperature threshold
        if (temp_c > 150)
        { 
            digitalWrite(buzzer, HIGH);
            digitalWrite(G_led, LOW);    
            digitalWrite(R_led, HIGH);  
        }
        else
        {  
            digitalWrite(G_led, HIGH);   
            digitalWrite(R_led, LOW);  
            digitalWrite(buzzer, LOW);
        }
        
        // Reset scale if switch is pressed
        if (digitalRead(sw) == LOW)
        {
            scale.set_scale();
            scale.tare();
        }
        
        // Write data to SD card
        Data = SD.open("DataAcquisition.txt", FILE_WRITE);
        Data.seek(EOF); // Move cursor to end of file
        if (Data)
        {
            Data.print(elapsedTime);
            Data.print(", ");
            Data.print(thrust, 2);
            Data.print(", ");
            Data.print(temp, 2);
            Data.print("\n");
            Data.close();
            Serial.println("Data Written Successfully");
        }
        else
        {
            Serial.println("Couldn't write data");
            Serial.println(" ");
        }
        
        delay(100);
    }
}

// Function to read temperature from thermocouple
double Thermocouple_read()
{
    uint16_t v_out;
    pinMode(CS, OUTPUT);
    pinMode(SO, INPUT);
    pinMode(SCK, OUTPUT);
    digitalWrite(CS, LOW);
    delay(1); 
    v_out = shiftIn(SO, SCK, MSBFIRST);
    v_out <<= 8;
    v_out |= shiftIn(SO, SCK, MSBFIRST);
    digitalWrite(CS, HIGH);
    if (v_out & 0x4) { 
        return NAN; // Return NaN if thermocouple connection issue
    }
    v_out >>= 3;
    return v_out * 0.2529; // Convert thermocouple reading to Celsius
}

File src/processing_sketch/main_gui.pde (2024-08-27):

import processing.serial.*;
Serial myPort;


void setup(){
  size(450, 500);
  myPort = new Serial(this, "COM5", 9600); // Starts the serial communication
  myPort.bufferUntil('\n'); // Defines up to which character the data from the serial port will be read. The character '\n' or 'New Line'
}


void draw(){
  background(237, 240, 241);
  fill(20, 160, 100); // Green Color
  stroke(33);
  strokeWeight(1);
  rect(100, 60, 250, 60, 10); // "START IGNITION" Button
  fill(255,0,0);
  rect(65, 140, 320, 60, 10); // "STOP DATA ACQUISITION" Button
  fill(0, 0, 255);
  rect(100, 220, 250, 60, 10); // "STOP IGNITION" Button
  fill(0,255,0);
  rect(50, 350, 150, 50, 10); // "Turn ON" Button
  fill(255,0,0);
  rect(250, 350, 150, 50, 10); // "Turn OFF" Button
  fill(255);
  
  textSize(28);
  text("START IGNITION",130, 100);
  text("STOP DATA ACQUISITION", 85, 180);
  text("STOP IGNITION",130, 260);
  text("Turn ON",73, 383);
  text("Turn OFF", 269, 383);
  textSize(24);
  fill(33);
  textSize(30);
  textSize(16);
  text("ROCKET MOTOR STATIC TEST BLUETOOTH CONTROL", 50, 40);
  text("FIRE EXTINGUISHER CONTROL BUTTONS", 90, 320);

  
  // If the button "START IGNITION" is pressed
  if(mousePressed && mouseX>100 && mouseX<350 && mouseY>60 && mouseY<120){
    myPort.write('1'); // Sends the character '1' to arduino, which then stops data acquisition.
    stroke(255,45,0);
    strokeWeight(2);
    noFill();
     rect(100, 60, 250, 60, 10);
  }
  // If the button "STOP DATA ACQUISITION" is pressed
  if(mousePressed && mouseX>65 && mouseX<385 && mouseY>140 && mouseY<200){
    myPort.write('0'); // Sends the character '0' to arduino, which then stops data acquisition.
    stroke(255,0,0);
    strokeWeight(2);
    noFill();
    rect(65, 140, 320, 60, 10);
  }
  // If the button "STOP IGNITION" is pressed
  if(mousePressed && mouseX>100 && mouseX<350 && mouseY>220 && mouseY<280){
    myPort.write('0'); // Sends the character 's' to arduino, which then stops data acquisition.
    stroke(255,0,0);
    strokeWeight(2);
    noFill();
    rect(100, 220, 250, 60, 10);
  }
   //If the button "Turn ON" is pressed 
    if(mousePressed && mouseX>50 && mouseX<200 && mouseY>350 && mouseY<400){
    myPort.write('o'); // Sends the character 'o' to arduino, which then turns on fire extinguisher.
    stroke(20,160,100);
    strokeWeight(2);
    noFill();
    rect(50, 350, 150, 50, 10);
  }
  // If the button "Turn OFF" is pressed
  if(mousePressed && mouseX>250 && mouseX<400 && mouseY>350 && mouseY<400){
    myPort.write('p'); // Sends the character 'p' to arduino, which then turns off fire extinguisher.
    stroke(255,0,0);
    strokeWeight(2);
    noFill();
    rect(250, 350, 150, 50, 10);
  }
}

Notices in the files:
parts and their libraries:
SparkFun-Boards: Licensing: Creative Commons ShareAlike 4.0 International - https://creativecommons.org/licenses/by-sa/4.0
